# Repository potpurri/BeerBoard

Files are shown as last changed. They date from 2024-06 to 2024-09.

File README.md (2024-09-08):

# BeerBoard

**BeerBoard** is a beer-shaped microcontroller breakout board based on the STM32F030C6T6. [Schematic can be found here.](https://github.com/potpurri/BeerBoard/blob/a81b2d54139fa46588d7e338071e49ddc263d606/Schematic_v02.pdf) Originally designed as a trophy for a beer quiz, its primary feature is blinking LEDs, adding a fun, interactive element to the prize. The project also served as an opportunity to experiment with JLCPCB's multicolor silkscreen options.

This board consists of **4 layers**, providing a robust platform for various applications beyond its original purpose. It also includes **breakout pins for I2C, SPI, and USART**, offering versatile connectivity options for external devices and peripherals. Below are images showing the assebled board, different silkscreen options and 3D renderings of the BeerBoard.

The board is soldered by me using a [Pinecil V2](https://wiki.pine64.org/wiki/Pinecil) by PINE64  and [MHP50](https://e-design.com.cn/en/Mini-Hot-Plate-Preheater-MHP50-PG9555615) by MiniWare.

## Features
- Beer-shaped PCB design
- STM32F030C6T6 microcontroller at its core
- Blinking LEDs for visual effects
- 4-layer PCB
- Available in both multicolor and regular silkscreen versions

## Images

### Assembled board
LED blinking gif
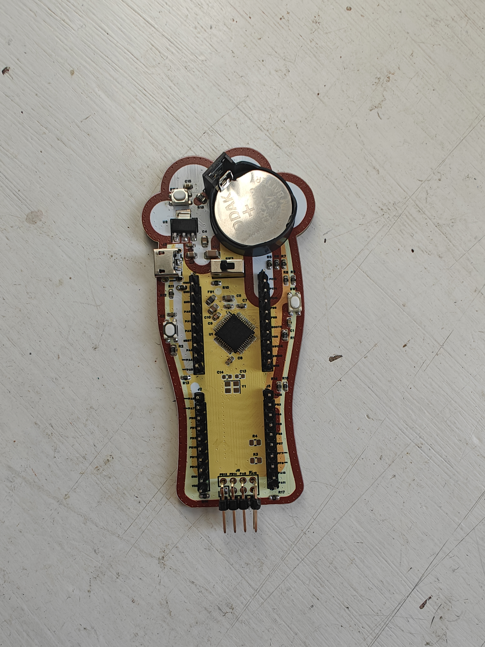
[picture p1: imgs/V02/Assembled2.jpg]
Assembled board back


### PCBs
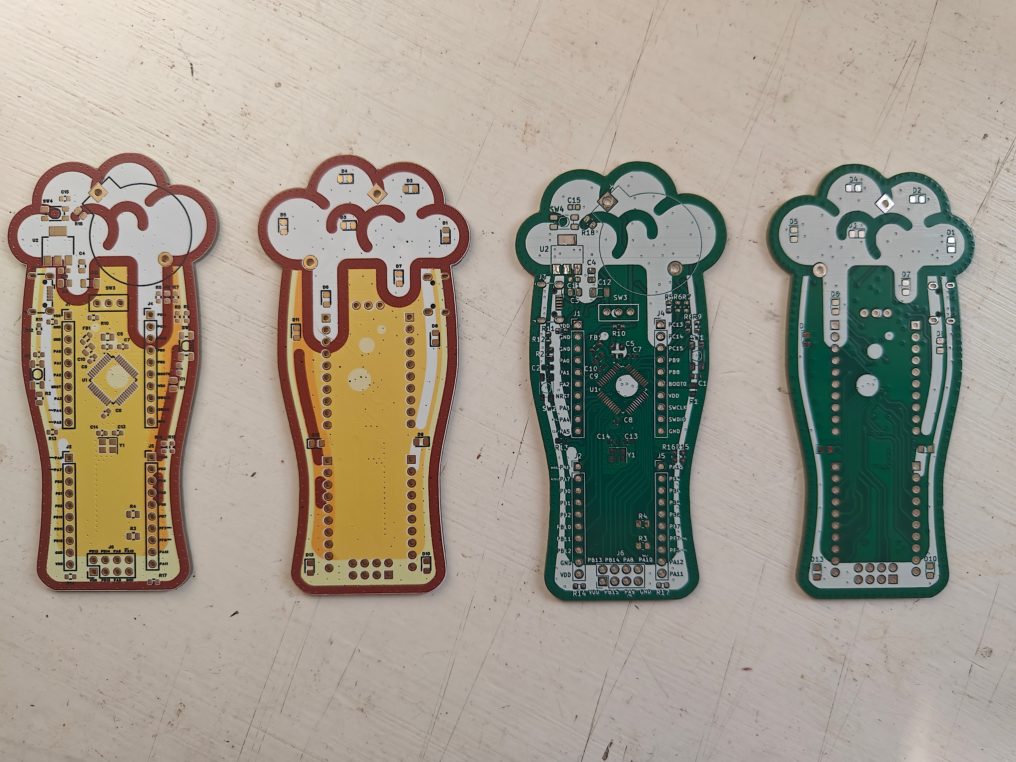
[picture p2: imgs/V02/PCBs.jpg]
BeerBoard PCB options


### 3D Renderings & Schematic
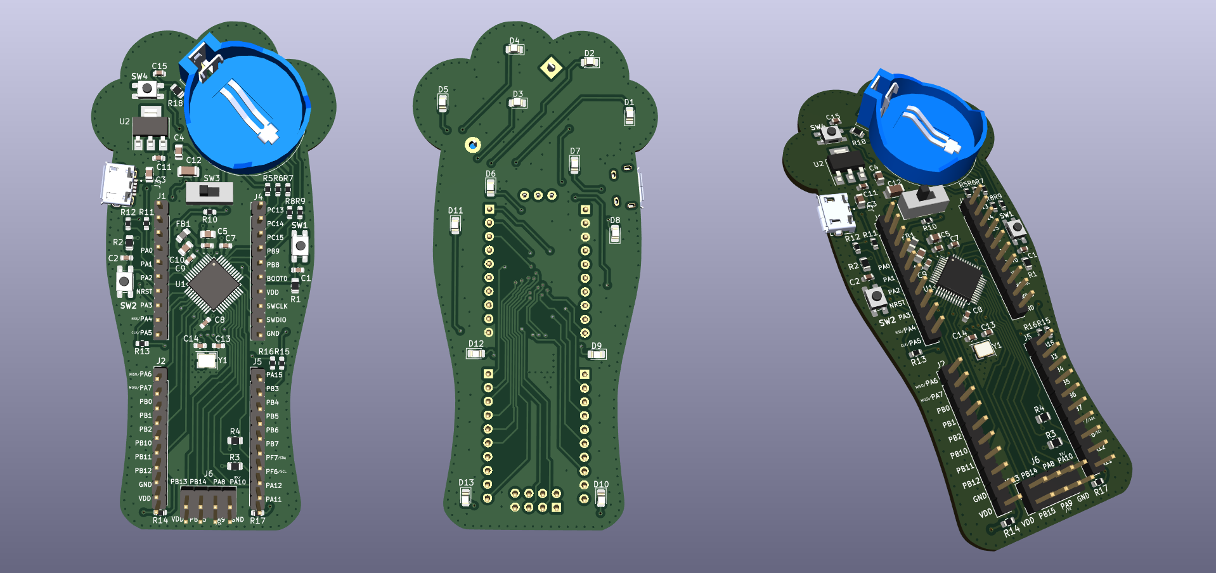
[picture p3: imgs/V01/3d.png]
3D Renderings of BeerBoard


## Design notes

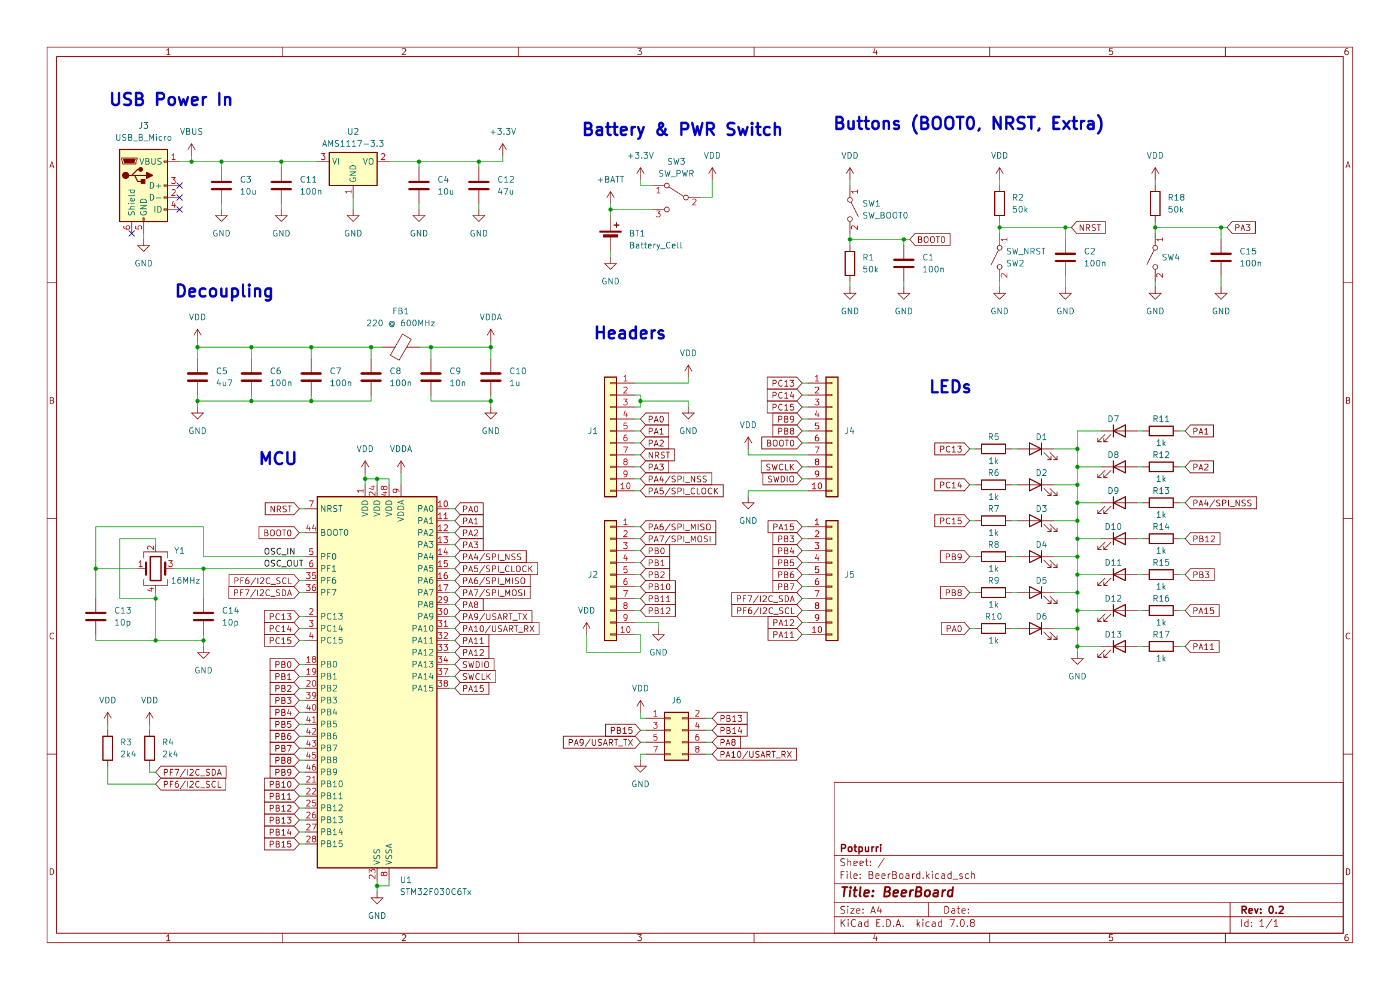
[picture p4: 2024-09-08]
imgs/V02/Schematic_v02.png

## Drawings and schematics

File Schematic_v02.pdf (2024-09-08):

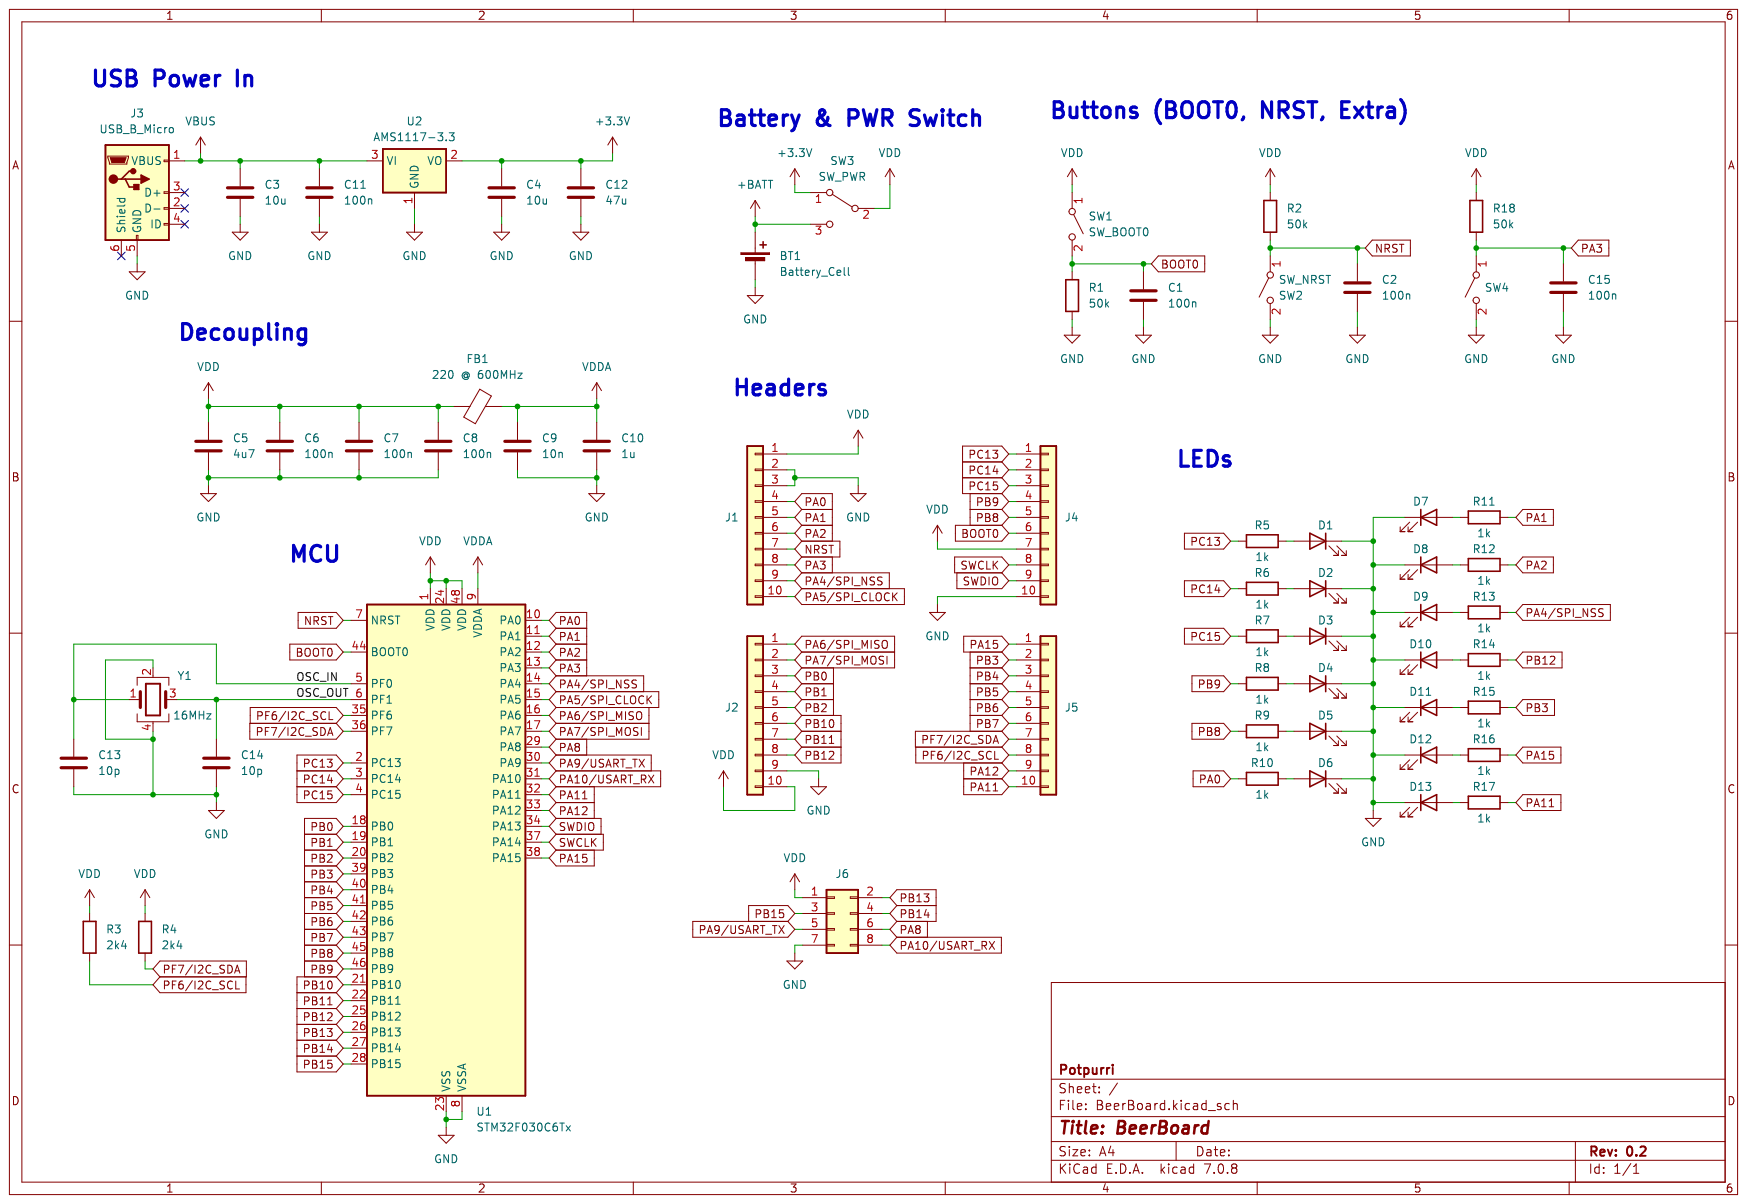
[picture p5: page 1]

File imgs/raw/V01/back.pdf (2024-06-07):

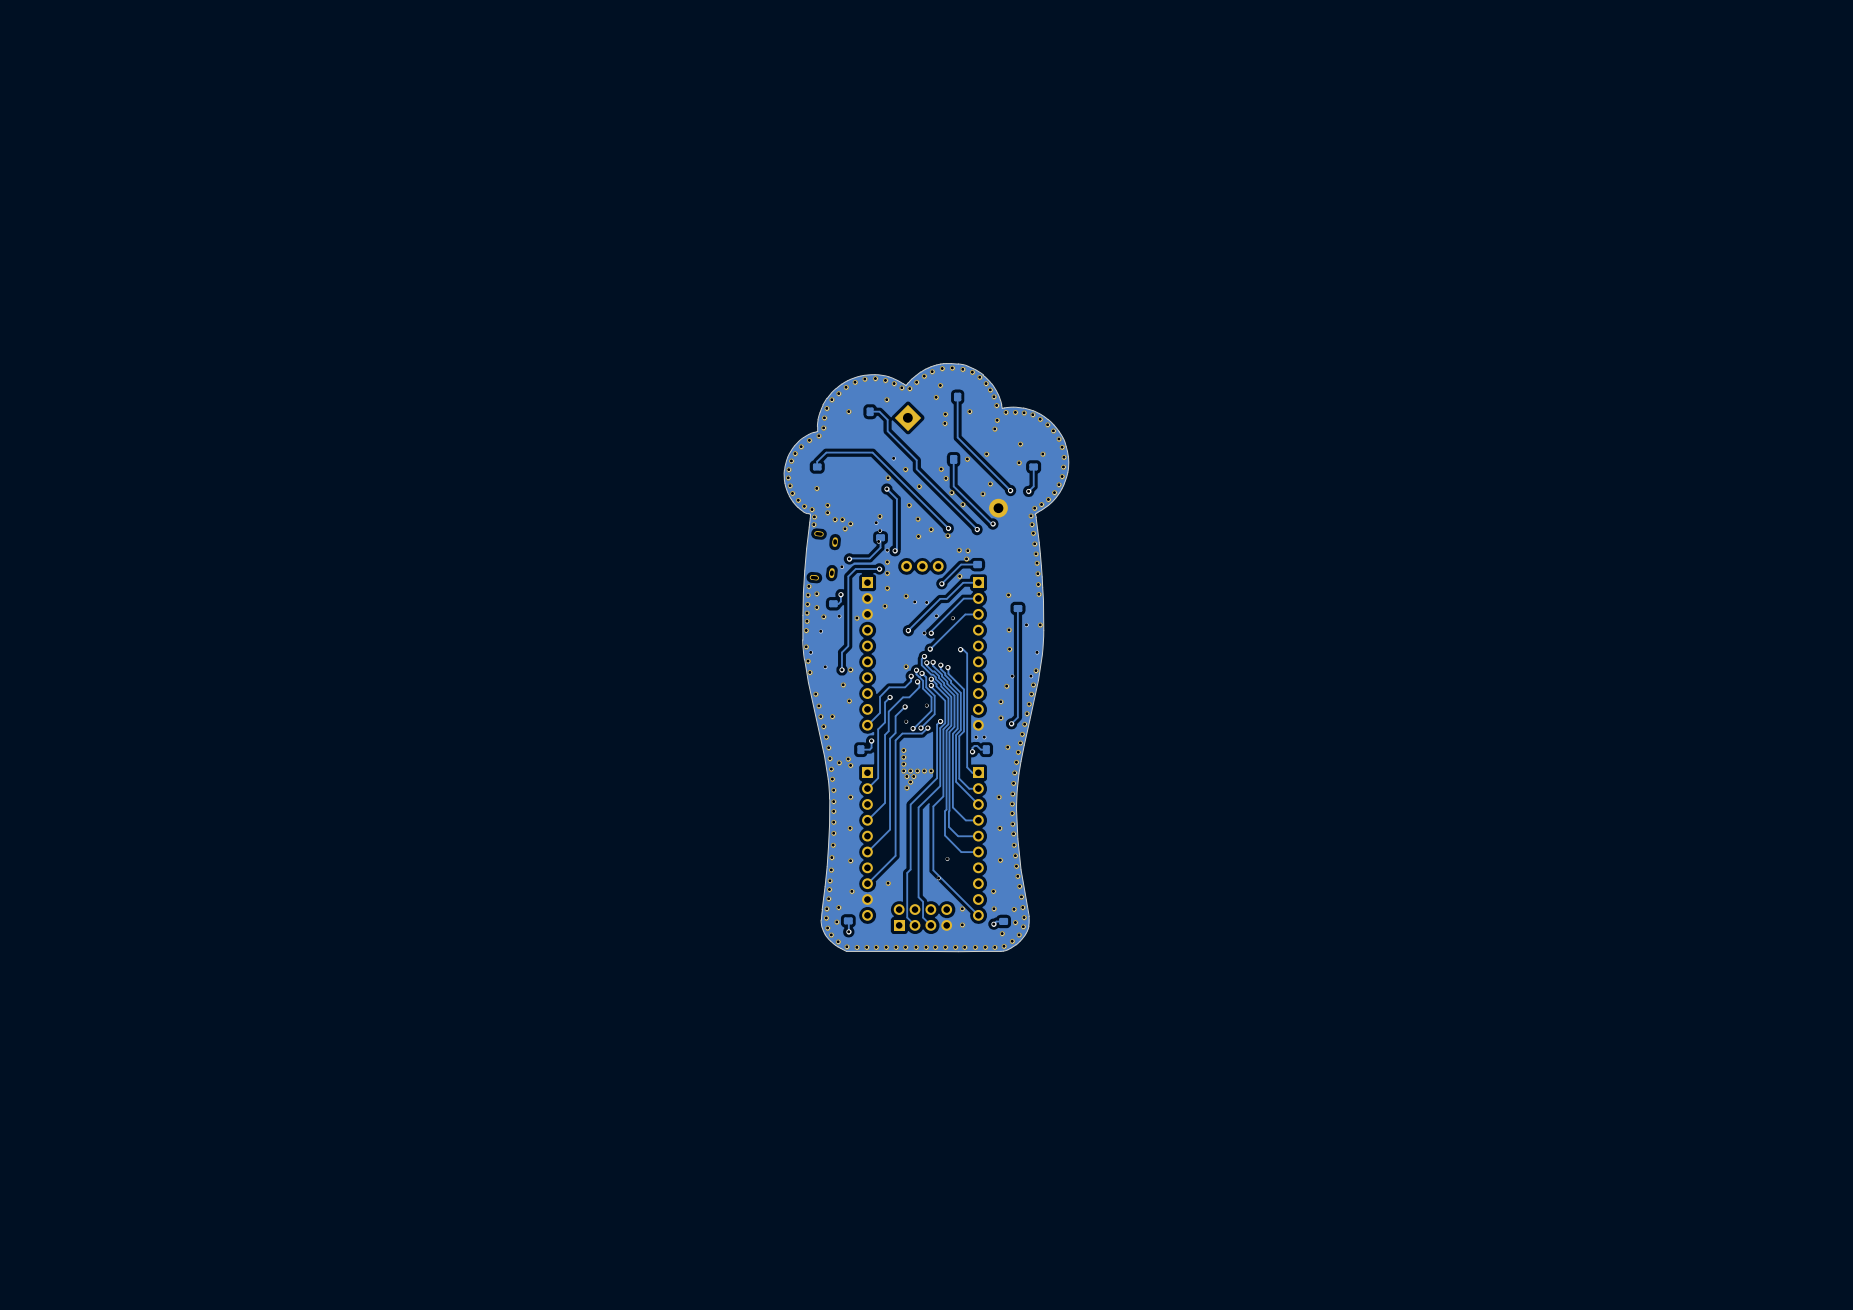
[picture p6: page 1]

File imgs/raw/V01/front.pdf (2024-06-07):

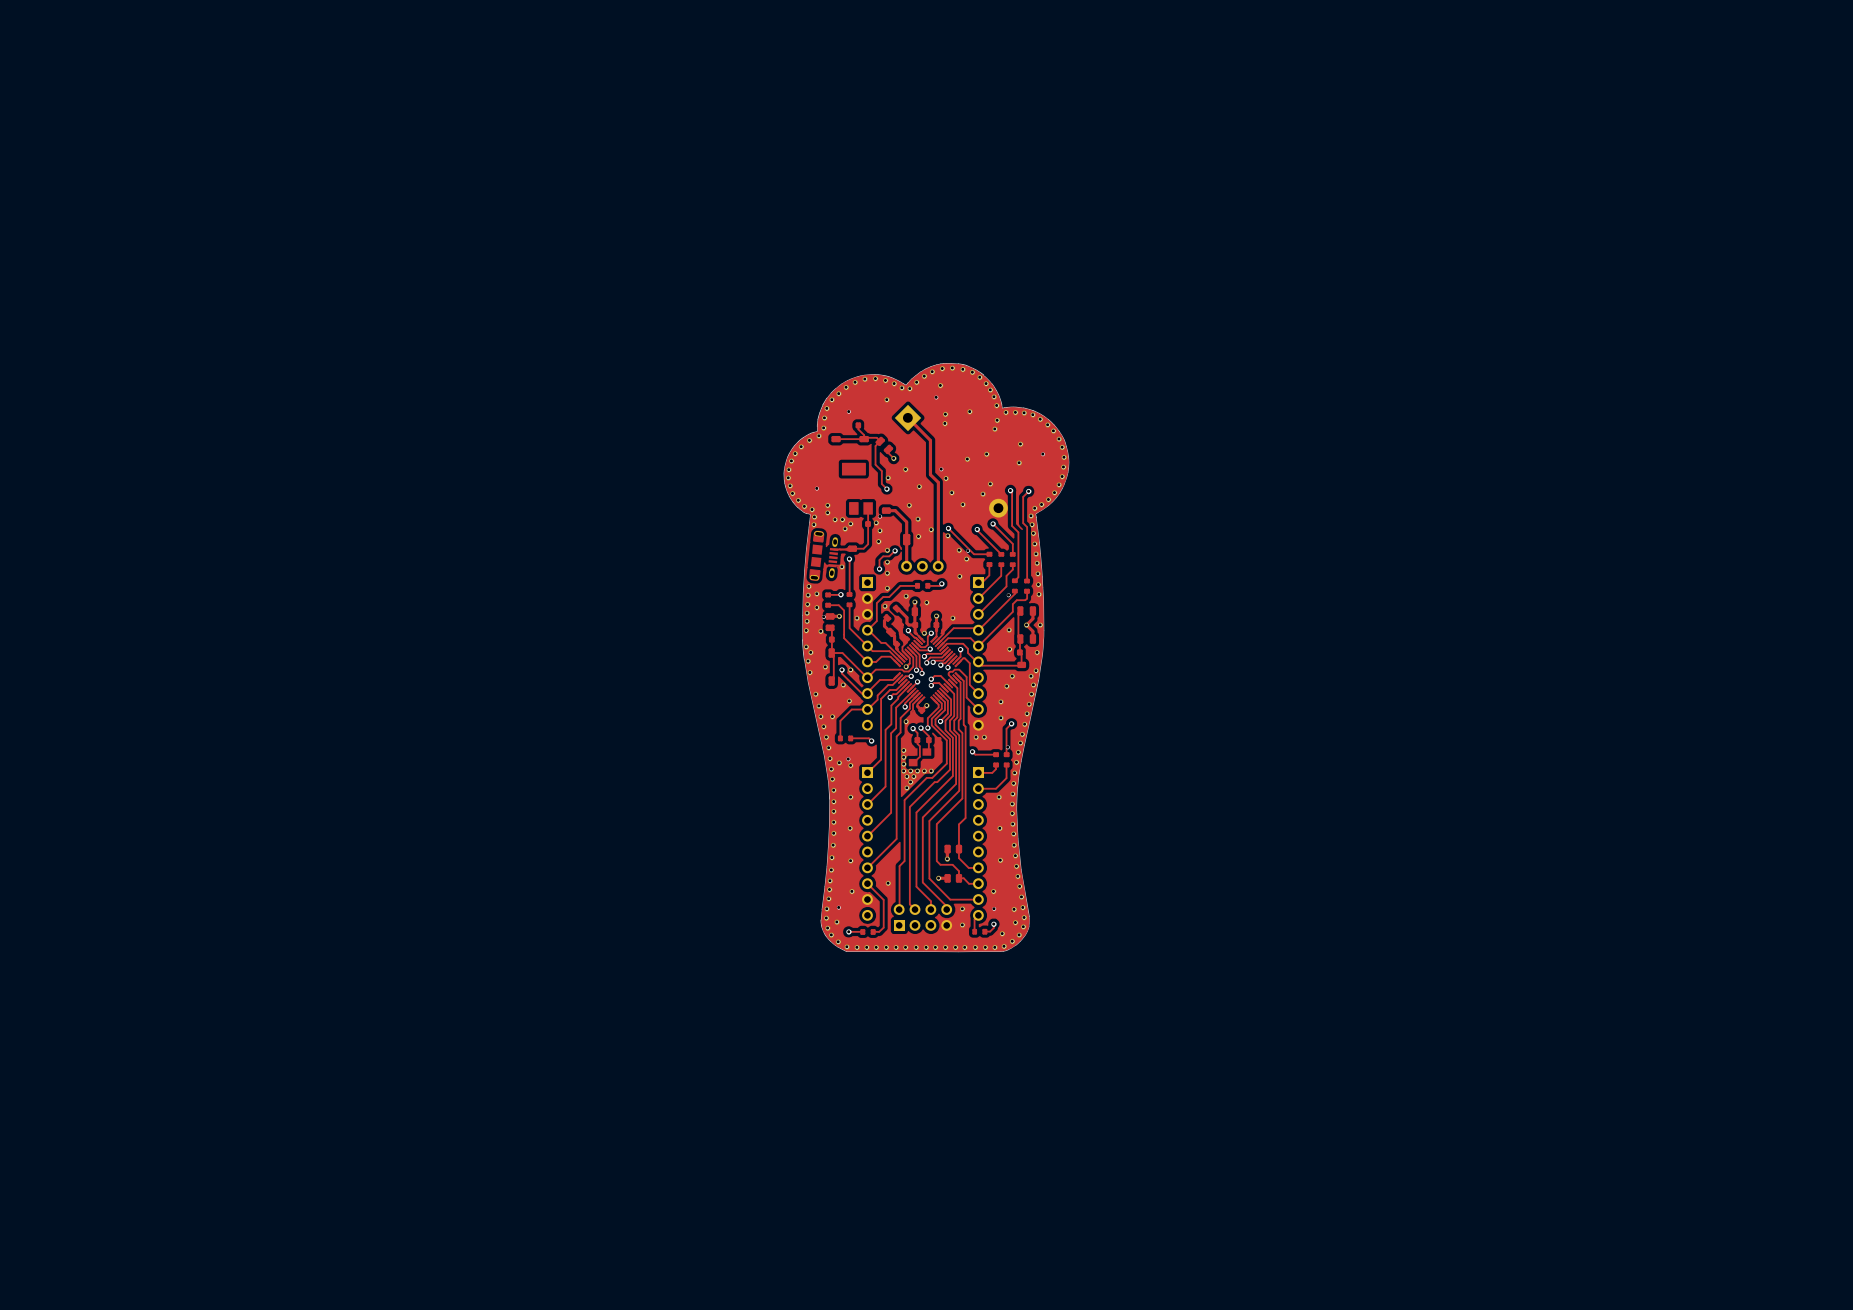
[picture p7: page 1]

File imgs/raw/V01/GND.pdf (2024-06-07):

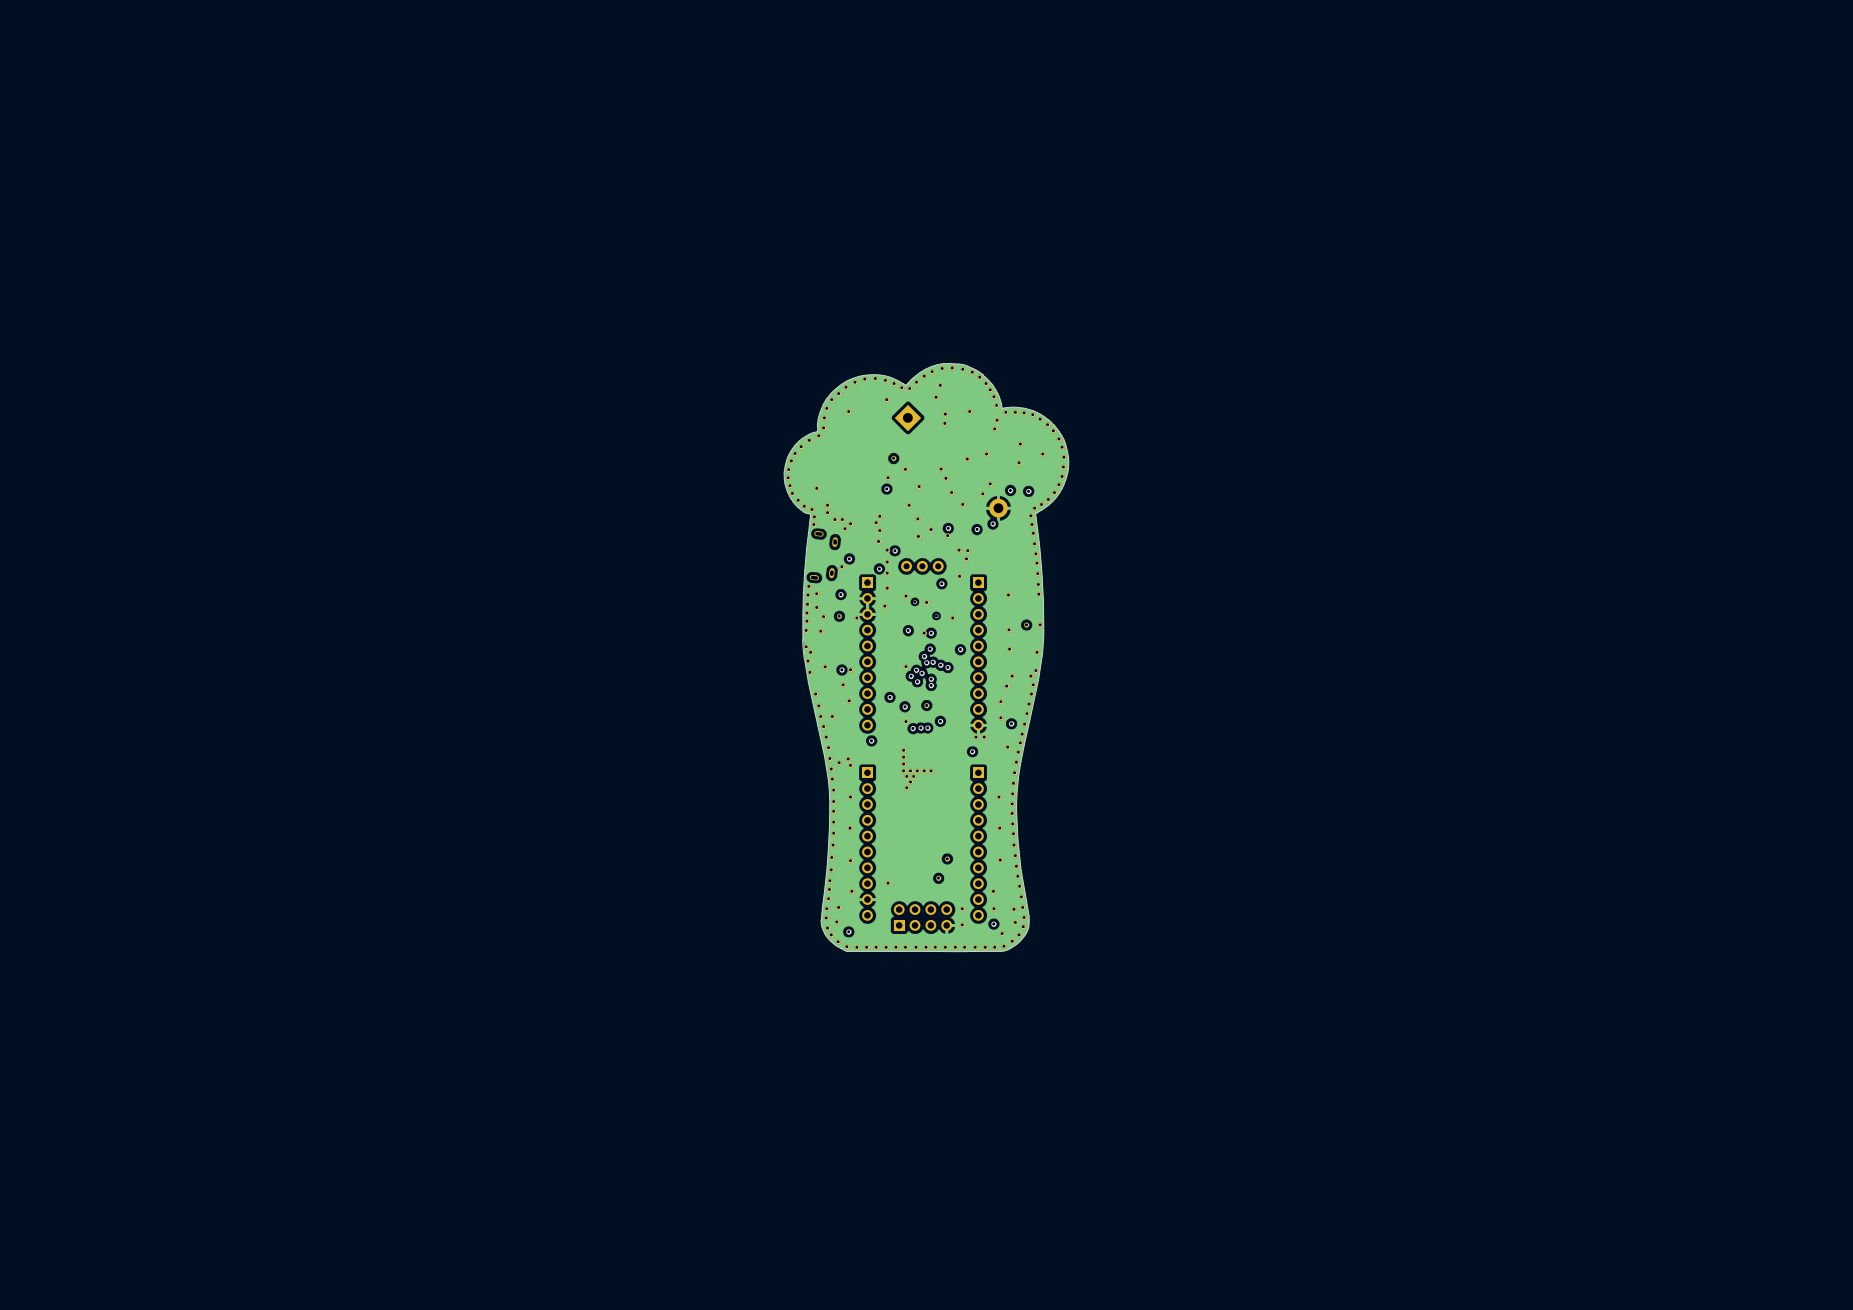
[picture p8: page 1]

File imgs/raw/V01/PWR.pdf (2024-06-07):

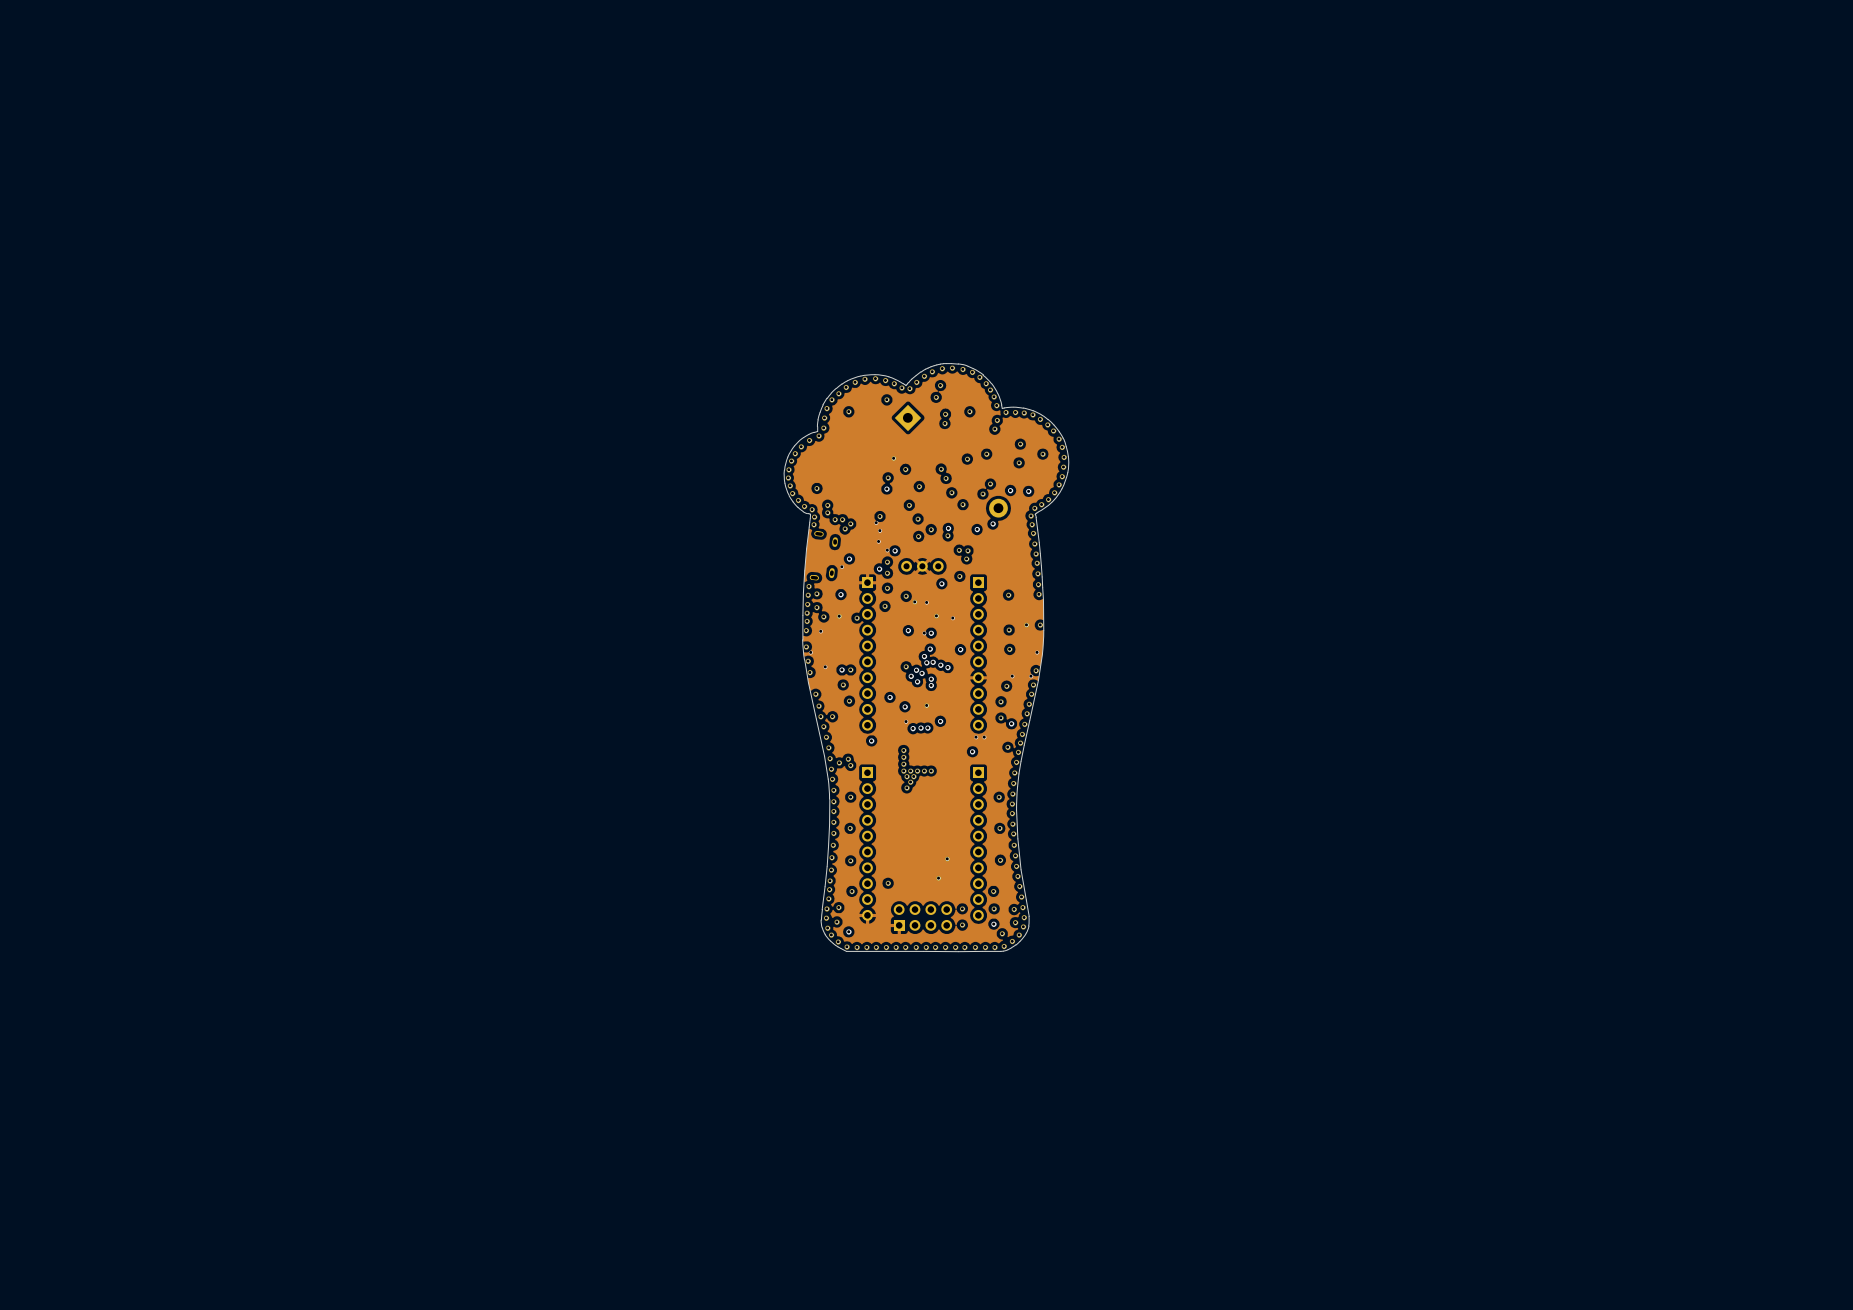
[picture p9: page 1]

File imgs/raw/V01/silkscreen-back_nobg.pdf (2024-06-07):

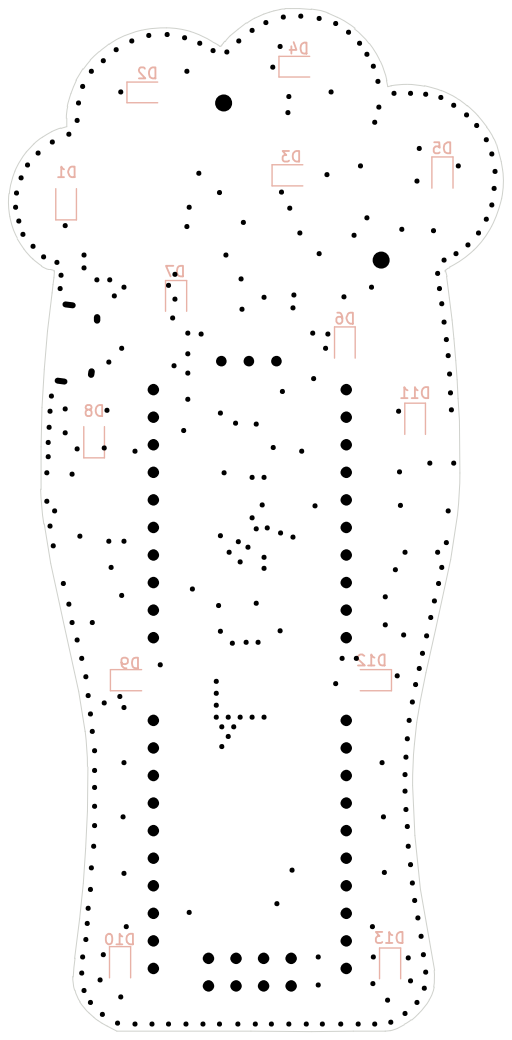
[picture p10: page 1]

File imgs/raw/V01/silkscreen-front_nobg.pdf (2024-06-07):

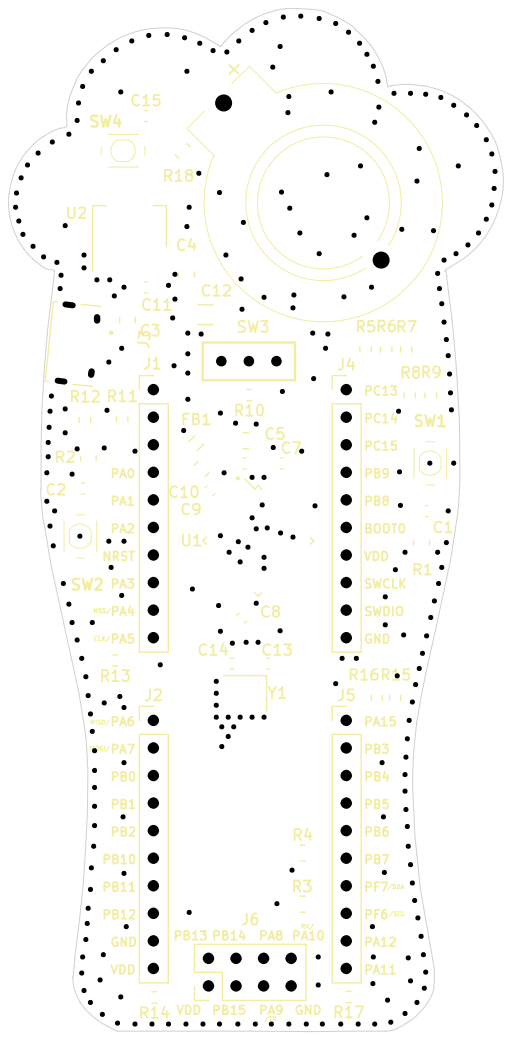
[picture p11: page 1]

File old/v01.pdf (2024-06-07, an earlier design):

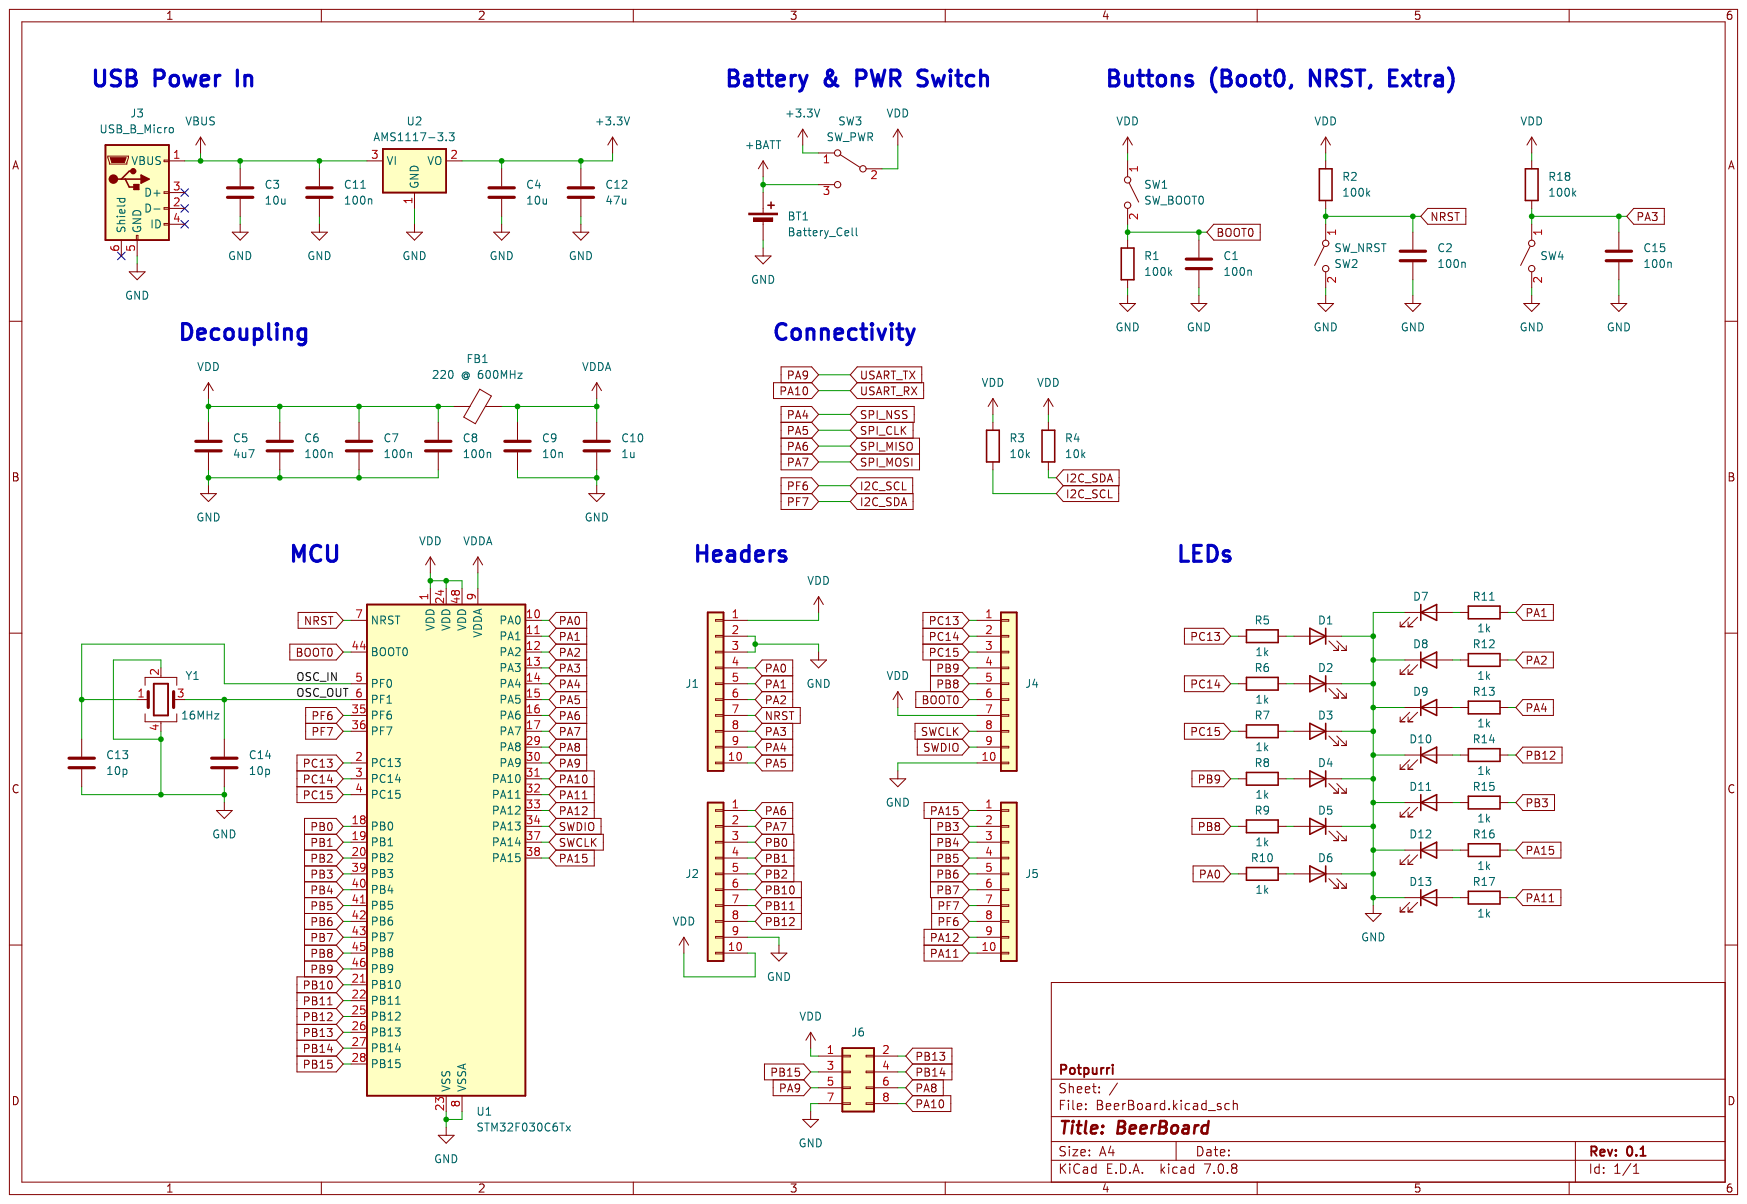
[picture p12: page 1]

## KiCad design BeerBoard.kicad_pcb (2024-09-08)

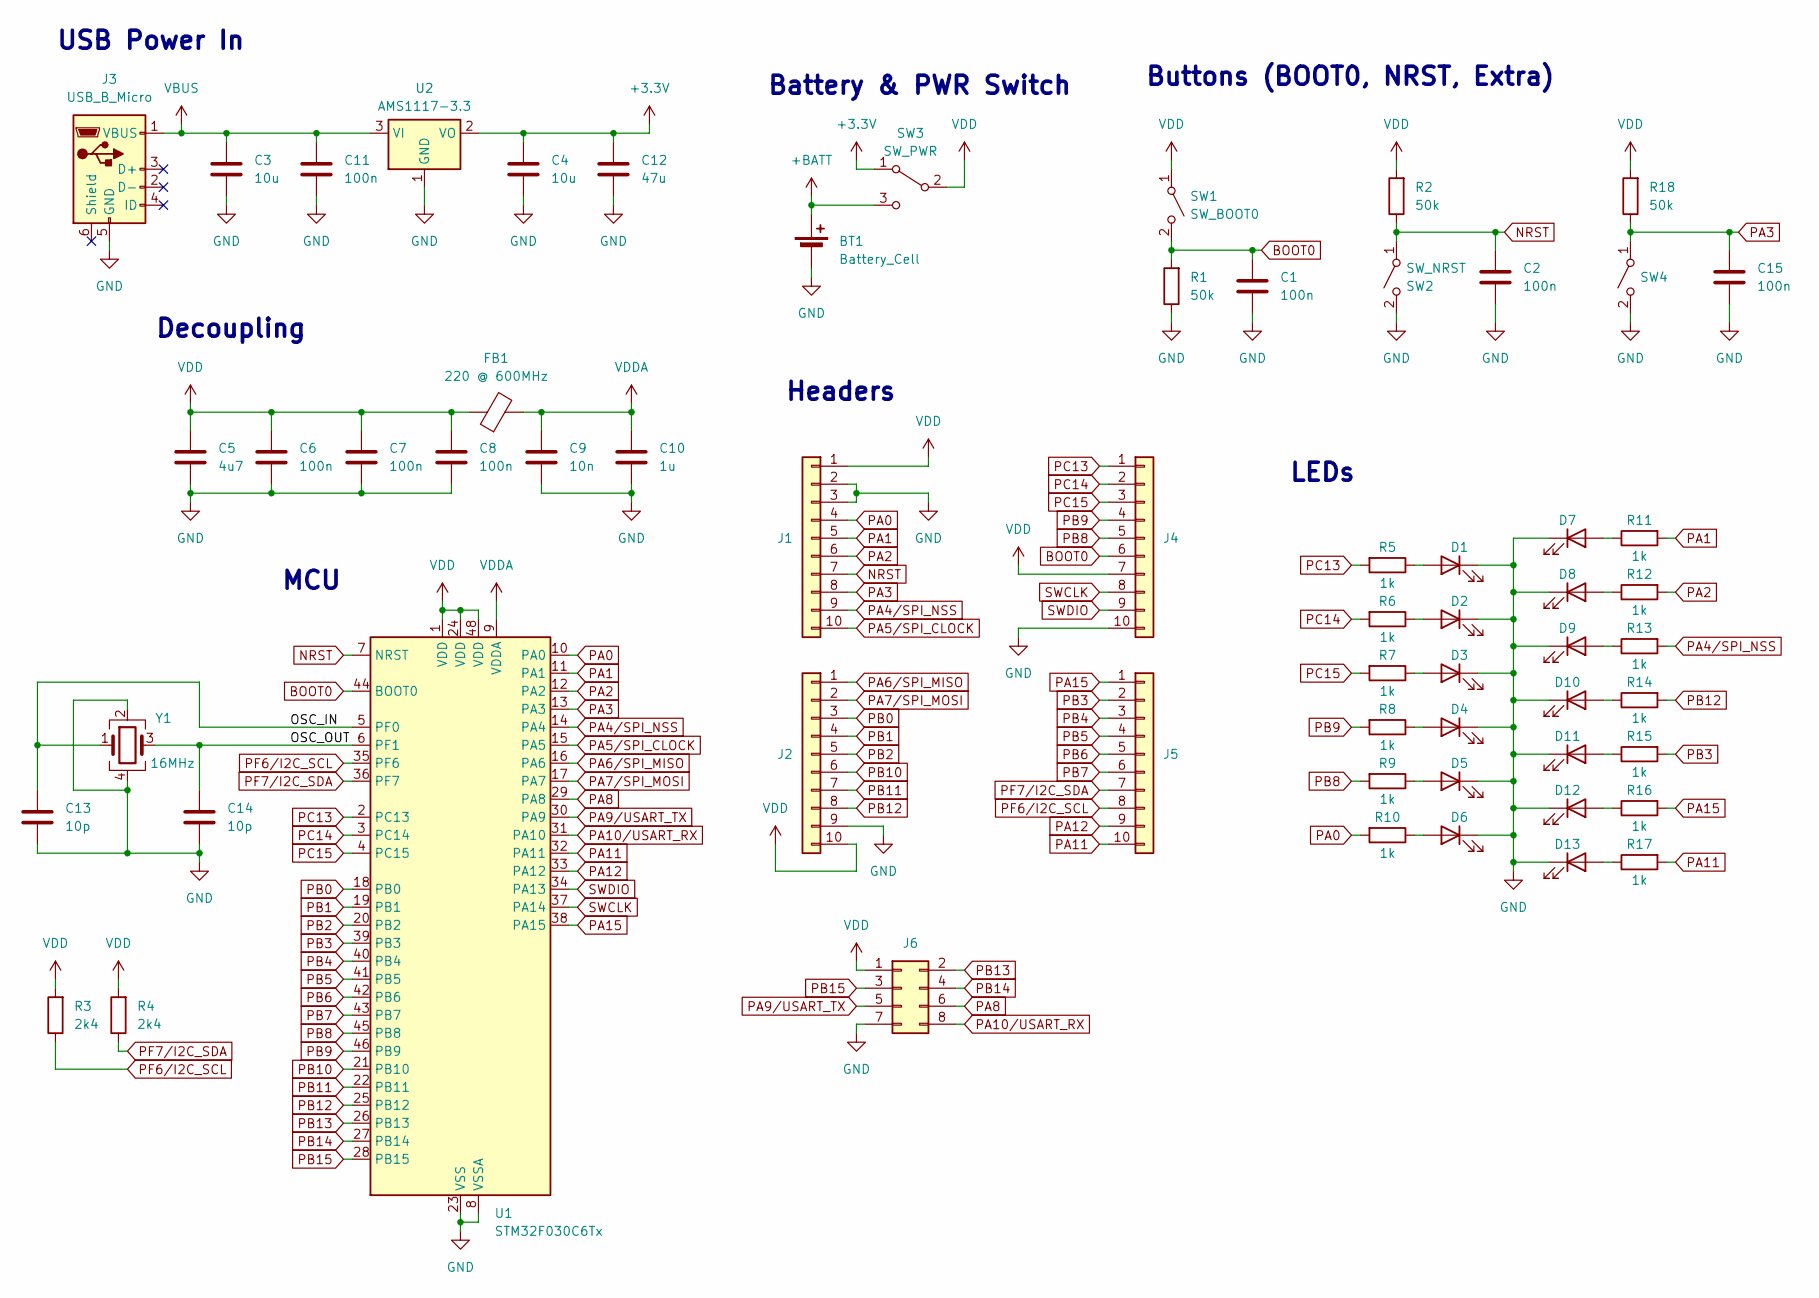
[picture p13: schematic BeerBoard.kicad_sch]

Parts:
BT1: Battery_Cell; CoinCell CR2032
C1, C2, C6, C7, C8, C11, C15: 100n; C_0603_1608Metric
C3, C4: 10u; C_0805_2012Metric
C5: 4u7; C_0805_2012Metric
C9: 10n; C_0603_1608Metric
C10: 1u; C_0805_2012Metric
C12: 47u; C_1206_3216Metric
C13, C14: 10p; C_0603_1608Metric
D1, D2, D3, D4, D5, D6, D7, D8, D9, D10, D11, D12, D13: LED; LED_0805_2012Metric_Pad1.15x1.40mm_HandSolder
FB1: 220 @ 600MHz; L_0805_2012Metric
J1, J2, J4, J5: Conn_01x10; PinHeader_1x10_P2.54mm_Vertical
J3: USB_B_Micro; USB_Micro-B_Wuerth_629105150521
J6: Conn_02x04_Odd_Even; PinHeader_2x04_P2.54mm_Vertical
R1, R2, R18: 50k; R_0805_2012Metric
R3, R4: 2k4; R_0805_2012Metric
R5, R6, R7, R8, R9, R10, R11, R12, R13, R14, R15, R16, R17: 1k; R_0603_1608Metric
SW1: SW_BOOT0; 3mm x 4mm micro switch button
SW2, SW4: SW_NRST; 3mm x 4mm micro switch button
SW3: SW_PWR; Schiebeschalter SS-12D00
U1: STM32F030C6Tx; LQFP-48_7x7mm_P0.5mm
U2: AMS1117-3.3; SOT-223-3_TabPin2
Y1: 16MHz; Crystal_SMD_3225-4Pin_3.2x2.5mm

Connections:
+3.3V: C4.1, C12.1, SW3.1 (A), U2.2 (VO)
+BATT: BT1.1 (+), SW3.3 (C)
/OSC_IN: C13.1, U1.5 (PF0), Y1.1
/OSC_OUT: C14.1, U1.6 (PF1), Y1.3
BOOT0: C1.1, J4.6, R1.2, SW1.2 (B), U1.44 (BOOT0)
GND: BT1.2 (-), C1.2, C2.2, C3.2, C4.2, C5.2, C6.2, C7.2, C8.2, C9.2, C10.2, C11.2, C12.2, C13.2, C14.2, C15.2, D1.1 (K), D2.1 (K), D3.1 (K), D4.1 (K), D5.1 (K), D6.1 (K), D7.1 (K), D8.1 (K), D9.1 (K), D10.1 (K), D11.1 (K), D12.1 (K), D13.1 (K), J1.2, J1.3, J2.9, J3.5 (GND), J4.10, J6.7, R1.1, SW2.2 (B), SW4.2 (B), U1.8 (VSSA), U1.23 (VSS), U1.47 (VSS), U2.1 (GND), Y1.2, Y1.4
NRST: C2.1, J1.7, R2.1, SW2.1 (A), U1.7 (NRST)
unnamed: D1.2 (A), R5.1
unnamed: D2.2 (A), R6.1
unnamed: D3.2 (A), R7.1
unnamed: D4.2 (A), R8.1
unnamed: D5.2 (A), R9.1
unnamed: D6.2 (A), R10.1
unnamed: D7.2 (A), R11.1
unnamed: D8.2 (A), R12.1
unnamed: D9.2 (A), R13.1
unnamed: D10.2 (A), R14.1
unnamed: D11.2 (A), R15.1
unnamed: D12.2 (A), R16.1
unnamed: D13.2 (A), R17.1
PA0: J1.4, R10.2, U1.10 (PA0)
PA1: J1.5, R11.2, U1.11 (PA1)
PA2: J1.6, R12.2, U1.12 (PA2)
PA3: C15.1, J1.8, R18.1, SW4.1 (A), U1.13 (PA3)
PA4/SPI_NSS: J1.9, R13.2, U1.14 (PA4)
PA5/SPI_CLOCK: J1.10, U1.15 (PA5)
PA6/SPI_MISO: J2.1, U1.16 (PA6)
PA7/SPI_MOSI: J2.2, U1.17 (PA7)
PA8: J6.6, U1.29 (PA8)
PA9/USART_TX: J6.5, U1.30 (PA9)
PA10/USART_RX: J6.8, U1.31 (PA10)
PA11: J5.10, R17.2, U1.32 (PA11)
PA12: J5.9, U1.33 (PA12)
PA15: J5.1, R16.2, U1.38 (PA15)
PB0: J2.3, U1.18 (PB0)
PB1: J2.4, U1.19 (PB1)
PB2: J2.5, U1.20 (PB2)
PB3: J5.2, R15.2, U1.39 (PB3)
PB4: J5.3, U1.40 (PB4)
PB5: J5.4, U1.41 (PB5)
PB6: J5.5, U1.42 (PB6)
PB7: J5.6, U1.43 (PB7)
PB8: J4.5, R9.2, U1.45 (PB8)
PB9: J4.4, R8.2, U1.46 (PB9)
PB10: J2.6, U1.21 (PB10)
PB11: J2.7, U1.22 (PB11)
PB12: J2.8, R14.2, U1.25 (PB12)
PB13: J6.2, U1.26 (PB13)
PB14: J6.4, U1.27 (PB14)
PB15: J6.3, U1.28 (PB15)
PC13: J4.1, R5.2, U1.2 (PC13)
PC14: J4.2, R6.2, U1.3 (PC14)
PC15: J4.3, R7.2, U1.4 (PC15)
PF6/I2C_SCL: J5.8, R3.1, U1.35 (PF6)
PF7/I2C_SDA: J5.7, R4.1, U1.36 (PF7)
SWCLK: J4.8, U1.37 (PA14)
SWDIO: J4.9, U1.34 (PA13)
VBUS: C3.1, C11.1, J3.1 (VBUS), U2.3 (VI)
VDD: C5.1, C6.1, C7.1, C8.1, FB1.1, J1.1, J2.10, J4.7, J6.1, R2.2, R3.2, R4.2, R18.2, SW1.1 (A), SW3.2 (B), U1.1 (VDD), U1.24 (VDD), U1.48 (VDD)
VDDA: C9.1, C10.1, FB1.2, U1.9 (VDDA)

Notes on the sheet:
MCU
Decoupling
USB Power In
Headers
Buttons (BOOT0, NRST, Extra)
LEDs
Battery & PWR Switch

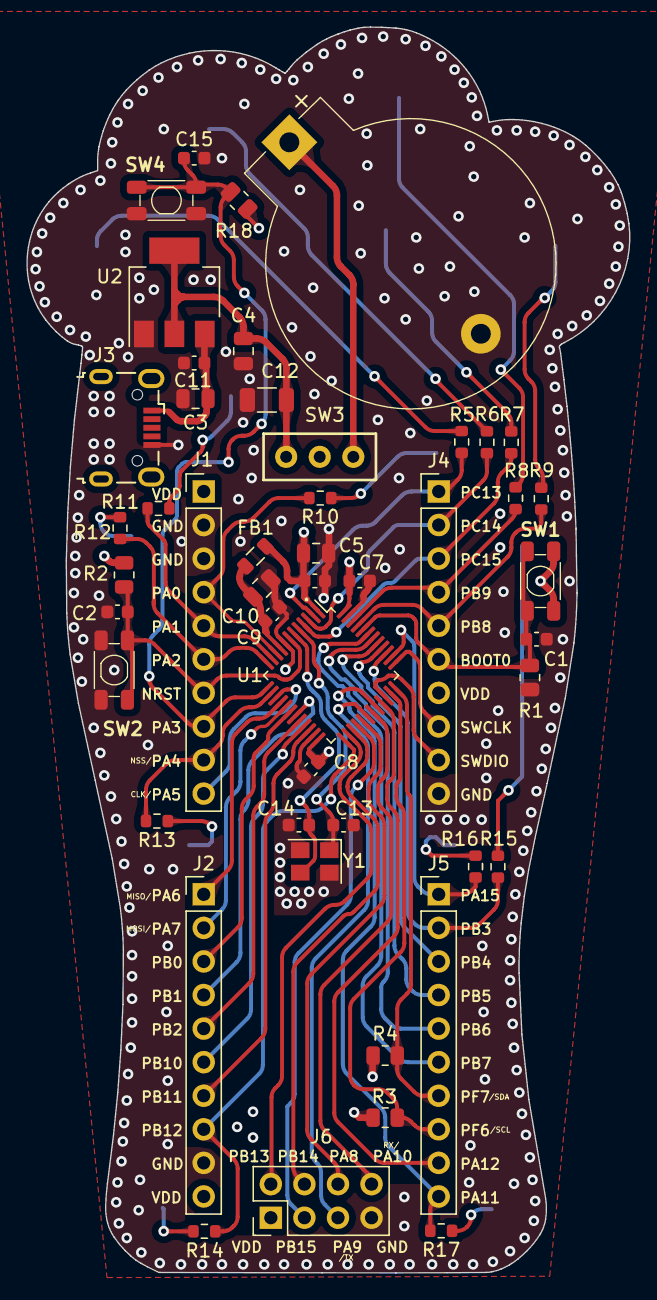
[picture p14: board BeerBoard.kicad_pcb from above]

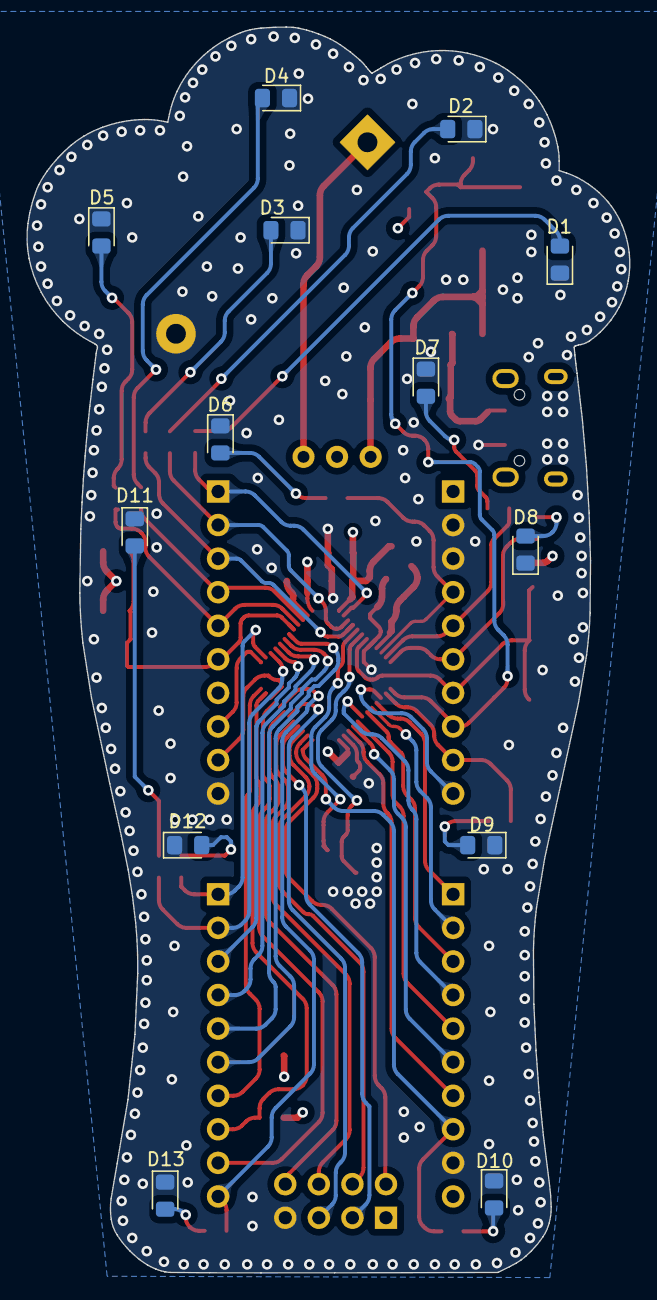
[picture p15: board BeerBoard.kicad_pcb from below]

Board: 4 copper layers, 45.6 x 94.3 mm, 61 parts (13 on the bottom side), 60 nets.

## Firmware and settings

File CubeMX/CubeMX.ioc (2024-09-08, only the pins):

Mcu.UserName=STM32F030C6Tx
PA0.GPIO_Label=D6
PA0.Signal=GPIO_Output
PA1.GPIO_Label=D7
PA1.Signal=GPIO_Output
PA10.GPIO_Label=D2_STND
PA10.Signal=GPIO_Output
PA11.GPIO_Label=D13
PA11.Signal=GPIO_Output
PA13.Signal=SYS_SWDIO
PA14.Signal=SYS_SWCLK
PA15.GPIO_Label=D12
PA15.Signal=GPIO_Output
PA2.GPIO_Label=D8
PA2.Signal=GPIO_Output
PA4.GPIO_Label=D9
PA4.Signal=GPIO_Output
PA5.Signal=SPI1_SCK
PA6.Signal=SPI1_MISO
PA7.Signal=SPI1_MOSI
PA8.GPIO_Label=D1_STND
PA8.Signal=GPIO_Output
PA9.GPIO_Label=D3_STND
PA9.Signal=GPIO_Output
PB12.GPIO_Label=D10
PB12.Signal=GPIO_Output
PB13.GPIO_Label=D5_STND
PB13.Signal=GPIO_Output
PB14.GPIO_Label=STND_CONNECTED
PB14.Signal=GPIO_Input
PB15.GPIO_Label=D4_STND
PB15.Signal=GPIO_Output
PB3.GPIO_Label=D11
PB3.Signal=GPIO_Output
PB8.GPIO_Label=D5
PB8.Signal=GPIO_Output
PB9.GPIO_Label=D4
PB9.Signal=GPIO_Output
PC13.GPIO_Label=D1
PC13.Signal=GPIO_Output
PC14-OSC32_IN.GPIO_Label=D2
PC14-OSC32_IN.Signal=GPIO_Output
PC15-OSC32_OUT.GPIO_Label=D3
PC15-OSC32_OUT.Signal=GPIO_Output
PF0-OSC_IN.Signal=RCC_OSC_IN
PF1-OSC_OUT.Signal=RCC_OSC_OUT
PF6.Signal=I2C1_SCL
PF7.Signal=I2C1_SDA

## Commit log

2024-06-07 created folder for old schematics
2024-06-08 v0.2 - ready for manufactoring
    [BeerBoard.kicad_pcb, BeerBoard.kicad_sch]
2024-09-08 version 0.2
    [BeerBoard.kicad_pcb, BeerBoard.kicad_sch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]
2024-09-08 added soldering to readme
